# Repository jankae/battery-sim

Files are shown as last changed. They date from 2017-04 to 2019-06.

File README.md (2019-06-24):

# battery-sim

## What is it?
The device emulates the behaviour of a battery, essentially it is a two quadrant supply with a configurable internal resistance.

Key features:
* Voltage range: 0 to 18V
* Current range: -3 to +3A
* Resistance range: 0.005 to 6Ohm

## Why was it built?
While developing other hardware meant to test batteries, various batteries in various different states (voltages, internal resistances, ...) were required to test some aspects. Normal batteries could have been used but getting them to (repeatedly!) behave in the necessary way would have been extremely time-consuming. So, this device was created.

It also doubles as a battery charger/discharger and general use supply.

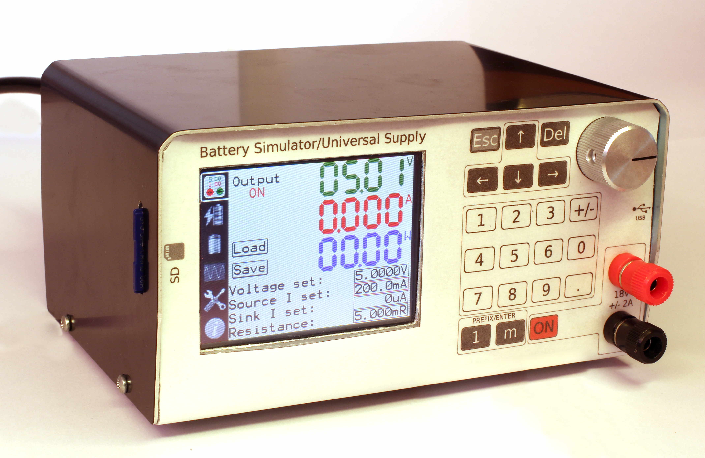
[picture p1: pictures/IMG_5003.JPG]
front1

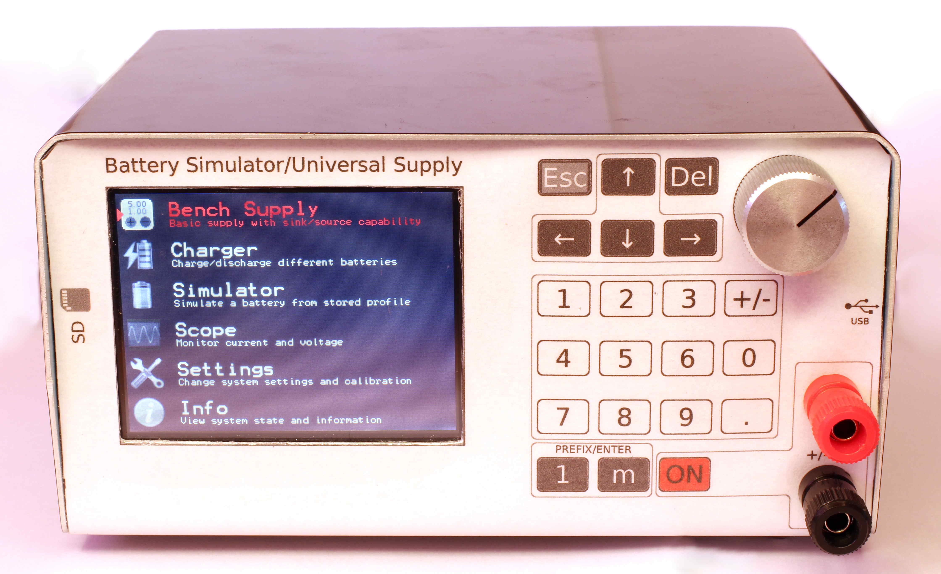
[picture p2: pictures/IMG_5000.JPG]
front2


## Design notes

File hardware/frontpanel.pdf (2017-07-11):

←

↑

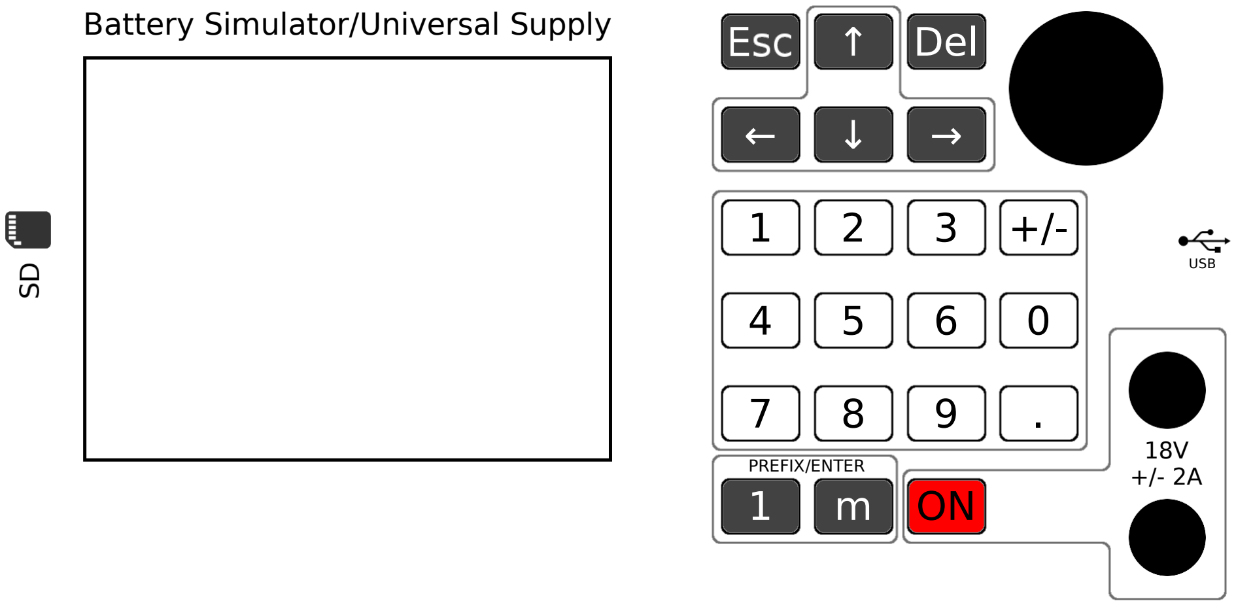
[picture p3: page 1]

Battery Simulator/Universal Supply

PREFIX/ENTER

18V
+/- 2A
ON
1 | 2 | 3
4 | 5 | 6
7 | 8 | 9

0

USB

+/-

→↓

### Del

1 m

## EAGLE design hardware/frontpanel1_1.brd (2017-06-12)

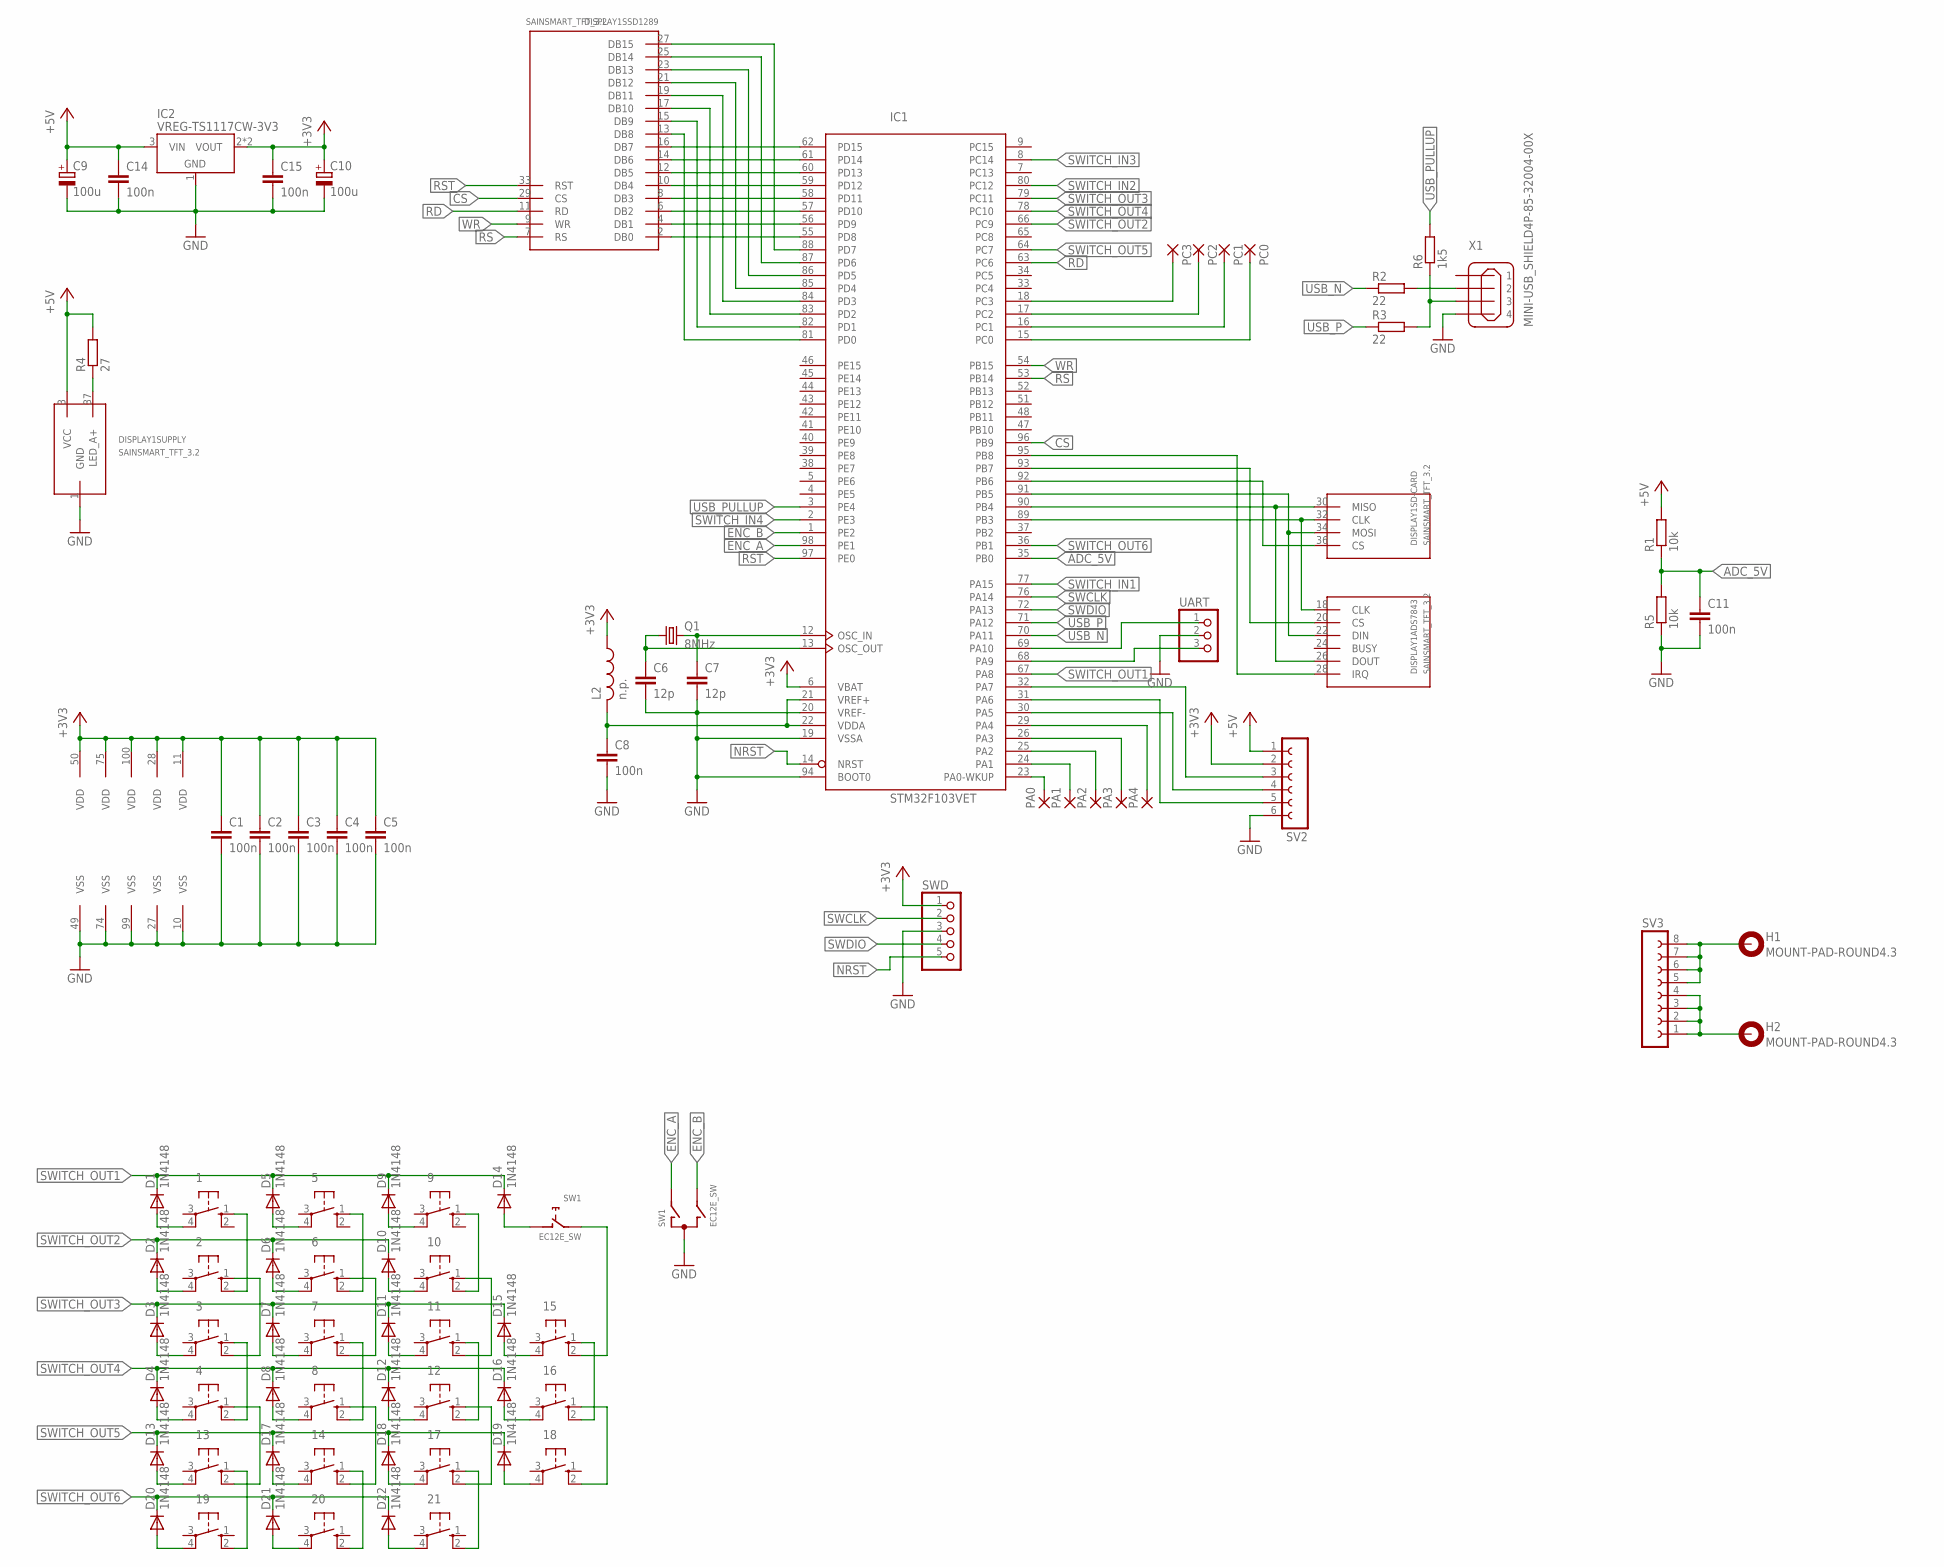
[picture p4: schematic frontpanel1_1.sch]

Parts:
1, 2, 3, 4, 5, 6, 7, 8, 9, 10, 11, 12, 13, 14, 15, 16, 17, 18, 19, 20, 21: 10-XXSMD; SMD
C1, C2, C3, C4, C5, C8, C11, C14, C15: 100n; C0603K
C6, C7: 12p; C0603K
C9, C10: 100u; 153CLV-0505
D1, D2, D3, D4, D5, D6, D7, D8, D9, D10, D11, D12, D13, D14, D15, D16, D17, D18, D19, D20, D21, D22: 1N4148; SOD323-W
DISPLAY1: SAINSMART_TFT_3.2
H1, H2: MOUNT-PAD-ROUND4.3; 4,3-PAD
IC1: STM32F103VET; LQFP100
IC2: VREG-TS1117CW-3V3; SOT223
L2: n.p.; R0603
PA0, PA1, PA2, PA3, PA4: SMD2; SMD1,27-2,54
PC0, PC1, PC2, PC3: SMD2; SMD1,27-2,54
Q1: 8MHz; SM49
R1, R5: 10k; R0603
R2, R3: 22; R0603
R4: 27; R1206
R6: 1k5; R0603
SV2: FE06-1; FE06
SV3: FE08-1; FE08
SW1: EC12E_SW; ALPS_EC12E_SW
SWD: PINHD-1X5; 1X05
UART: PINHD-1X3; 1X03
X1: MINI-USB_SHIELD4P-85-32004-00X; 85-32004-00X

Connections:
+3V3: C1.1, C2.1, C3.1, C4.1, C5.1, C10.+, C15.1, IC1.6 (VBAT), IC1.11 (VDD), IC1.28 (VDD), IC1.50 (VDD), IC1.75 (VDD), IC1.100 (VDD), IC2.2 (VOUT), IC2.4 (VOUT), L2.1, SV2.2, SWD.1
+5V: C9.+, C14.1, DISPLAY1.3 (VCC), IC2.3 (VIN), R1.2, R4.2, SV2.1
ADC_5V: C11.1, IC1.35 (PB0), R1.1, R5.2
CS: DISPLAY1.29 (CS), IC1.96 (PB9)
ENC_A: IC1.98 (PE1), SW1.A
ENC_B: IC1.1 (PE2), SW1.B
EXT4: C8.1, IC1.21 (VREF+), IC1.22 (VDDA), L2.2
GND: C1.2, C2.2, C3.2, C4.2, C5.2, C6.2, C7.2, C8.2, C9.-, C10.-, C11.2, C14.2, C15.2, DISPLAY1.1 (GND), IC1.10 (VSS), IC1.19 (VSSA), IC1.20 (VREF-), IC1.27 (VSS), IC1.49 (VSS), IC1.74 (VSS), IC1.94 (BOOT0), IC1.99 (VSS), IC2.1 (GND), R5.1, SV2.6, SW1.C, SWD.3, UART.2, X1.4
MISO: IC1.31 (PA6), SV2.5
MOSI: IC1.32 (PA7), SV2.3
unnamed: IC1.15 (PC0), PC0.1
unnamed: C7.1, IC1.12 (OSC_IN), Q1.2
unnamed: C6.1, IC1.13 (OSC_OUT), Q1.1
unnamed: DISPLAY1.2 (DB0), IC1.55 (PD8)
unnamed: DISPLAY1.4 (DB1), IC1.56 (PD9)
unnamed: DISPLAY1.6 (DB2), IC1.57 (PD10)
unnamed: DISPLAY1.8 (DB3), IC1.58 (PD11)
unnamed: DISPLAY1.10 (DB4), IC1.59 (PD12)
unnamed: DISPLAY1.12 (DB5), IC1.60 (PD13)
unnamed: DISPLAY1.14 (DB6), IC1.61 (PD14)
unnamed: DISPLAY1.16 (DB7), IC1.62 (PD15)
unnamed: DISPLAY1.15 (DB9), IC1.82 (PD1)
unnamed: DISPLAY1.17 (DB10), IC1.83 (PD2)
unnamed: DISPLAY1.13 (DB8), IC1.81 (PD0)
unnamed: DISPLAY1.19 (DB11), IC1.84 (PD3)
unnamed: DISPLAY1.21 (DB12), IC1.85 (PD4)
unnamed: DISPLAY1.23 (DB13), IC1.86 (PD5)
unnamed: DISPLAY1.25 (DB14), IC1.87 (PD6)
unnamed: DISPLAY1.27 (DB15), IC1.88 (PD7)
unnamed: 13.1 (S), 19.2 (S1)
unnamed: 4.1 (S), 13.2 (S1)
unnamed: 13.4 (P1), D13.A
unnamed: 14.4 (P1), D17.A
unnamed: 17.4 (P1), D18.A
unnamed: 18.4 (P1), D19.A
unnamed: 19.4 (P1), D20.A
unnamed: 20.4 (P1), D21.A
unnamed: 21.4 (P1), D22.A
unnamed: IC1.16 (PC1), PC1.1
unnamed: IC1.17 (PC2), PC2.1
unnamed: IC1.18 (PC3), PC3.1
unnamed: IC1.23 (PA0-WKUP), PA0.1
unnamed: 2.1 (S), 3.2 (S1)
unnamed: 1.1 (S), 2.2 (S1)
unnamed: 5.1 (S), 6.2 (S1)
unnamed: 6.1 (S), 7.2 (S1)
unnamed: IC1.24 (PA1), PA1.1
unnamed: 8.1 (S), 14.2 (S1)
unnamed: 14.1 (S), 20.2 (S1)
unnamed: 17.1 (S), 21.2 (S1)
unnamed: IC1.25 (PA2), PA2.1
unnamed: R2.2, X1.2
unnamed: R3.2, R6.1, X1.3
unnamed: DISPLAY1.37 (LED_A+), R4.1
unnamed: IC1.26 (PA3), PA3.1
unnamed: DISPLAY1.22 (DIN), DISPLAY1.34 (MOSI), IC1.91 (PB5)
unnamed: 4.4 (P1), D4.A
unnamed: 3.4 (P1), D3.A
unnamed: 2.4 (P1), D2.A
unnamed: 1.4 (P1), D1.A
unnamed: DISPLAY1.26 (DOUT), DISPLAY1.30 (MISO), IC1.90 (PB4)
unnamed: DISPLAY1.18 (CLK), DISPLAY1.32 (CLK), IC1.89 (PB3)
unnamed: 11.1 (S), 12.2 (S1)
unnamed: 8.4 (P1), D8.A
unnamed: 7.4 (P1), D7.A
unnamed: 6.4 (P1), D6.A
unnamed: 5.4 (P1), D5.A
unnamed: 10.1 (S), 11.2 (S1)
unnamed: 9.1 (S), 10.2 (S1)
unnamed: 15.1 (S), 16.2 (S1)
unnamed: 12.4 (P1), D12.A
unnamed: 11.4 (P1), D11.A
unnamed: 10.4 (P1), D10.A
unnamed: 9.4 (P1), D9.A
unnamed: IC1.29 (PA4), PA4.1
unnamed: DISPLAY1.36 (CS), IC1.92 (PB6)
unnamed: DISPLAY1.20 (CS), IC1.93 (PB7)
unnamed: 16.4 (P1), D16.A
unnamed: 15.4 (P1), D15.A
unnamed: D14.A, SW1.D (1)
unnamed: DISPLAY1.28 (IRQ), IC1.95 (PB8)
unnamed: 15.2 (S1), SW1.E (2)
NRST: IC1.14 (NRST), SWD.5
OUT+: H2.B4,3, SV3.1, SV3.2, SV3.3, SV3.4
OUT-: H1.B4,3, SV3.5, SV3.6, SV3.7, SV3.8
RD: DISPLAY1.11 (RD), IC1.63 (PC6)
RS: DISPLAY1.7 (RS), IC1.53 (PB14)
RST: DISPLAY1.33 (RST), IC1.97 (PE0)
RX: IC1.69 (PA10), UART.1
SCK: IC1.30 (PA5), SV2.4
SWCLK: IC1.76 (PA14), SWD.2
SWDIO: IC1.72 (PA13), SWD.4
SWITCH_IN1: 3.1 (S), 4.2 (S1), IC1.77 (PA15)
SWITCH_IN2: 7.1 (S), 8.2 (S1), IC1.80 (PC12)
SWITCH_IN3: 12.1 (S), 17.2 (S1), IC1.8 (PC14)
SWITCH_IN4: 16.1 (S), 18.2 (S1), IC1.2 (PE3)
SWITCH_OUT1: D1.C, D5.C, D9.C, D14.C, IC1.67 (PA8)
SWITCH_OUT2: D2.C, D6.C, D10.C, IC1.66 (PC9)
SWITCH_OUT3: D3.C, D7.C, D11.C, D15.C, IC1.79 (PC11)
SWITCH_OUT4: D4.C, D8.C, D12.C, D16.C, IC1.78 (PC10)
SWITCH_OUT5: D13.C, D17.C, D18.C, D19.C, IC1.64 (PC7)
SWITCH_OUT6: D20.C, D21.C, D22.C, IC1.36 (PB1)
TX: IC1.68 (PA9), UART.3
USB_N: IC1.70 (PA11), R2.1
USB_P: IC1.71 (PA12), R3.1
USB_PULLUP: IC1.3 (PE4), R6.2
WR: DISPLAY1.9 (WR), IC1.54 (PB15)

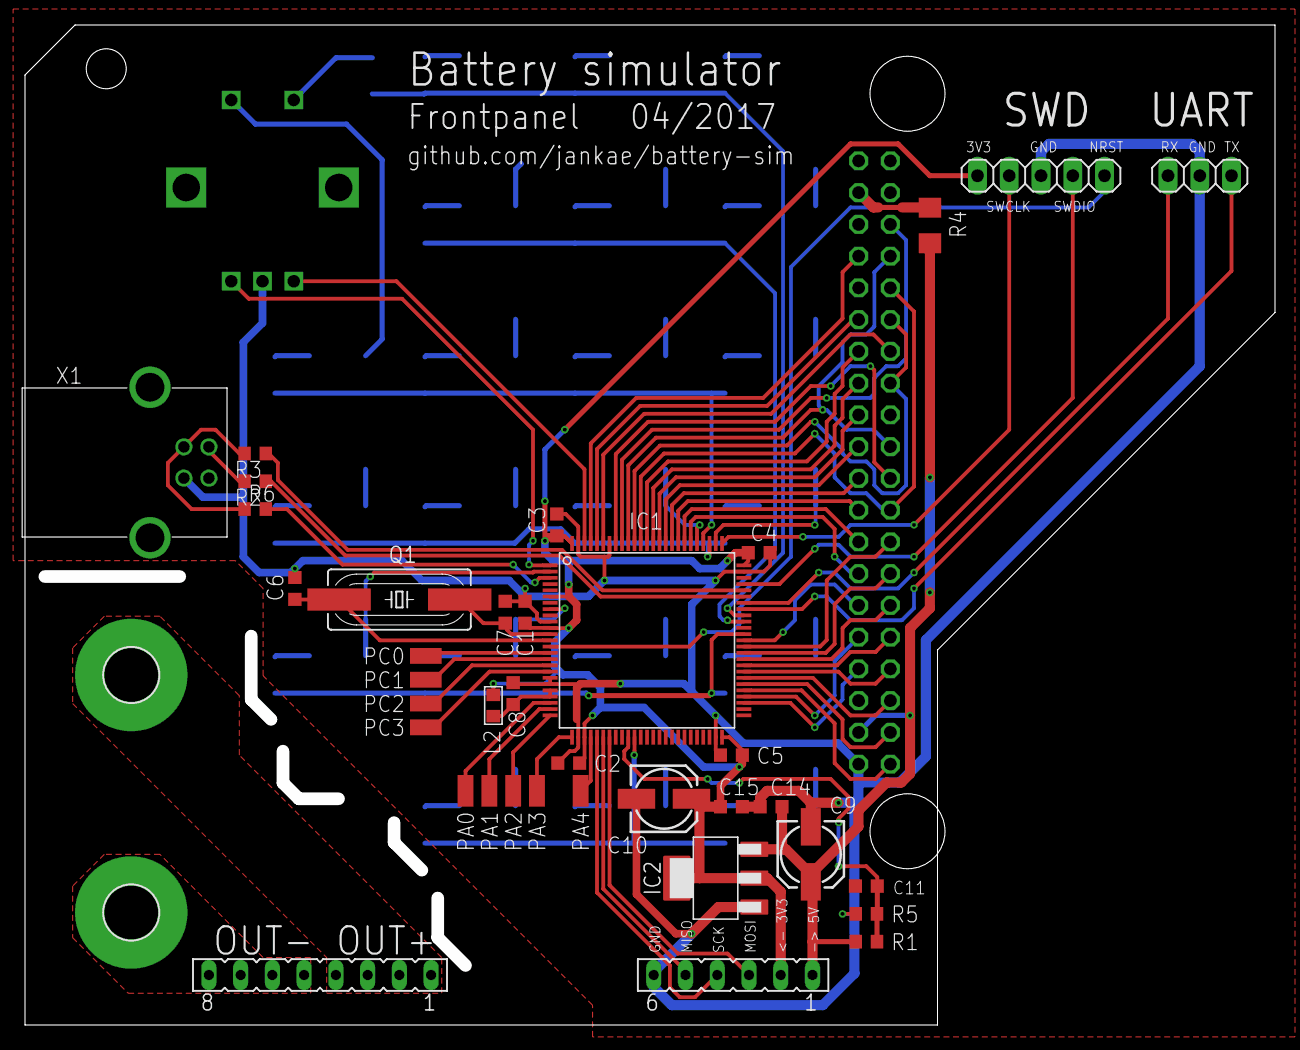
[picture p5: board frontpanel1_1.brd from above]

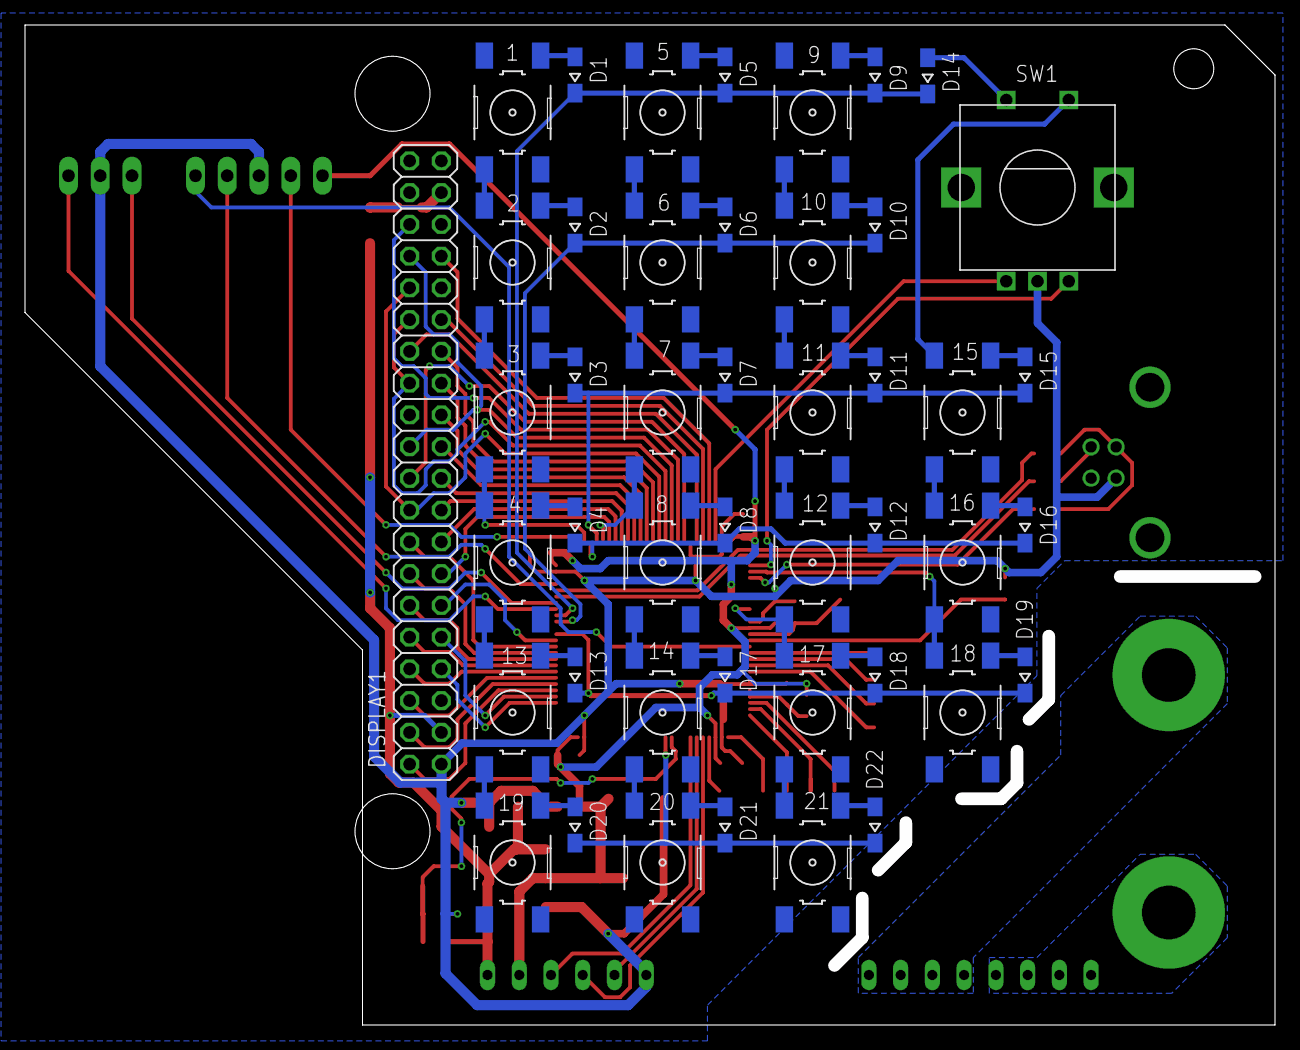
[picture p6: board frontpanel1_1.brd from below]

Board: 2 copper layers, 100.0 x 80.0 mm, 84 parts (45 on the bottom side), 107 nets.

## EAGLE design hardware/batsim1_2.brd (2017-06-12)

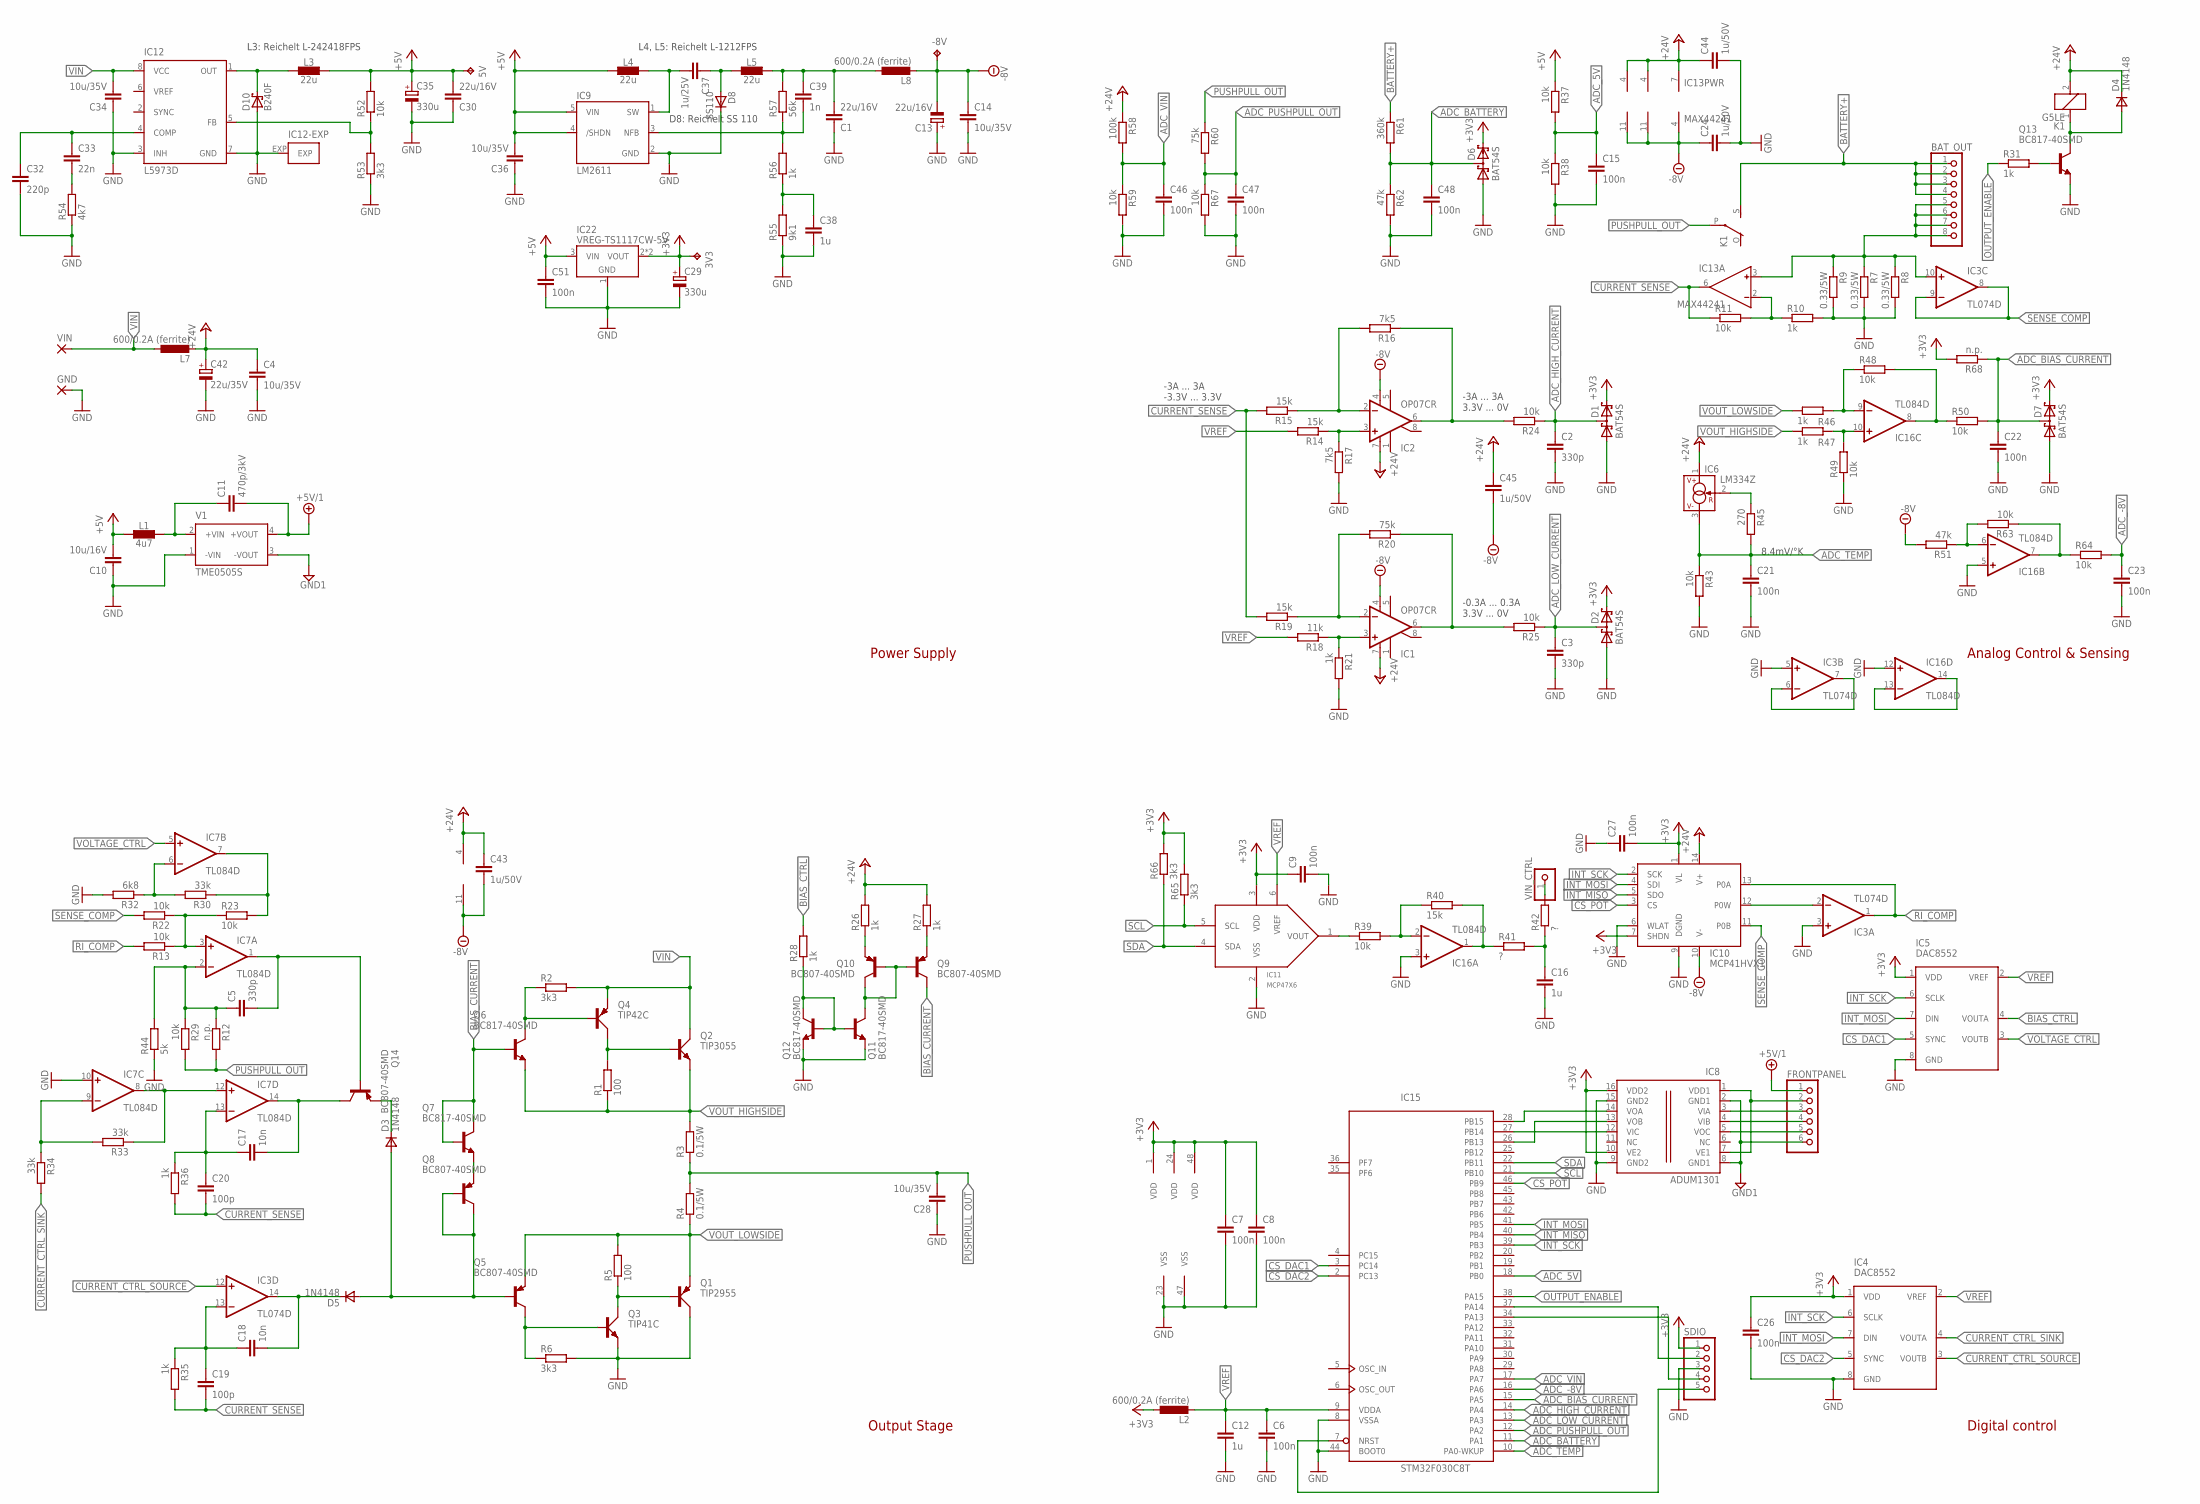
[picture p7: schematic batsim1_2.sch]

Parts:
3V3, 5V: TPB1,27; B1,27
-8V: TPB1,27; B1,27
BAT_OUT: PINHD-1X8/90; 1X08/90
C1, C30: 22u/16V; C1206
C2, C3, C5: 330p; C0603
C4, C14, C28, C34, C36: 10u/35V; C1206
C6, C7, C8, C9, C15, C21, C22, C23, C26, C27, C46, C47, C48, C51: 100n; C0603
C10: 10u/16V; C1206
C11: 470p/3kV; C1812
C12, C16, C38: 1u; C0603
C13: 22u/16V; 153CLV-0505
C17, C18: 10n; C0603
C19, C20: 100p; C0603
C24, C43, C44, C45: 1u/50V; C0603
C29, C35: 330u; 153CLV-0605
C32: 220p; C0603
C33: 22n; C0603
C37: 1u/25V; C1206
C39: 1n; C0603
C42: 22u/35V; 153CLV-0605
D1, D2, D6, D7: BAT54S; SOT23
D3, D4, D5: 1N4148; SOD323
D8: SS110; SMA
D10: B240F; SMB
FRONTPANEL: PINHD-1X6/90; 1X06/90
GND: 3,81/1,4
IC1, IC2: OP07CR; SO08
IC3: TL074D; SO14
IC4, IC5: DAC8552; MSOP8
IC6: LM334Z; TO92
IC7, IC16: TL084D; SO14
IC8: ADUM1301; SO-16W
IC9: LM2611; SOT23-5
IC10: MCP41HVX1; TSSOP14
IC11: MCP47X6; SOT23-6L
IC12: L5973D; HSOP8
IC13: MAX44241; UMAX8
IC15: STM32F030C8T; LQFP48
IC22: VREG-TS1117CW-5V; SOT223
K1: G5LE
L1: 4u7; L_1212
L2, L7, L8: 600/0.2A (ferrite); L2012C
L3: 22u; L_NR60XX
L4, L5: 22u; L_1212
Q1: TIP2955; TOP3AV
Q2: TIP3055; TOP3AV
Q3: TIP41C; TO220AV
Q4: TIP42C; TO220AV
Q5, Q8, Q9, Q10, Q14: BC807-40SMD; SOT23-BEC
Q6, Q7, Q11, Q12, Q13: BC817-40SMD; SOT23-BEC
R1, R5: 100; R0603
R2, R6, R53, R65, R66: 3k3; R0603
R3, R4: 0.1/5W; 5WAXIAL
R7, R8, R9: 0.33/5W; 5WAXIAL
R10, R21, R26, R27, R28, R31, R35, R36, R46, R47, R56: 1k; R0603
R11, R13, R22, R23, R24, R25, R29, R37, R38, R39, R43, R48, R49, R50, R52, R59, R63, R64, R67: 10k; R0603
R12, R68: n.p.; R0603
R14, R15, R19, R40: 15k; R0603
R16, R17: 7k5; R0603
R18: 11k; R0603
R20, R60: 75k; R0603
R30, R33, R34: 33k; R0603
R32: 6k8; R0603
R41, R42: ?; R0603
R44: 5k; R0603
R45: 270; R0603
R51, R62: 47k; R0603
R54: 4k7; R0603
R55: 9k1; R0603
R57: 56k; R0603
R58: 100k; R0603
R61: 360k; R0603
SDIO: PINHD-1X5; 1X05
V1: TME0505S; TME
VIN: 3,81/1,4
VIN_CTRL: PINHD-1X1; 1X01

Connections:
+3V3: 3V3.TP, C7.1, C8.1, C9.1, C26.1, C27.2, C29.+, D1.2 (C2), D2.2 (C2), D6.2 (C2), D7.2 (C2), IC4.1 (VDD), IC5.1 (VDD), IC8.10 (VE2), IC8.16 (VDD2), IC10.1 (VL), IC10.7 (SHDN), IC11.3 (VDD), IC15.1 (VDD), IC15.24 (VDD), IC15.48 (VDD), IC22.2 (VOUT), IC22.4 (VOUT), L2.1, R65.2, R66.2, R68.2, SDIO.1
+5V: 5V.TP, C10.2, C30.2, C35.+, C36.2, C51.1, IC9.4 (/SHDN), IC9.5 (VIN), IC22.3 (VIN), L1.1, L3.2, L4.1, R37.1, R52.2
+5V/1: C11.2, FRONTPANEL.1, V1.4 (+VOUT)
+24V: C4.1, C42.+, C43.1, C44.1, C45.1, D4.1 (C), IC1.7 (V+), IC2.7 (V+), IC3.4 (V+), IC6.1 (V+), IC7.4 (V+), IC10.14 (V+), IC13.7 (V+), IC16.4 (V+), K1.2, L7.2, R26.2, R27.2, R58.1
-8V: -8V.TP, C13.-, C14.1, C24.1, C43.2, C45.2, IC1.4 (V-), IC2.4 (V-), IC3.11 (V-), IC7.11 (V-), IC10.10 (V-), IC13.4 (V-), IC16.11 (V-), L8.2, R51.2
ADC_5V: C15.1, IC15.18 (PB0), R37.2, R38.1
ADC_-8V: C23.1, IC15.16 (PA6), R64.2
ADC_BATTERY: C48.1, D6.3 (C1A2), IC15.11 (PA1), R61.2, R62.1
ADC_BIAS_CURRENT: C22.1, D7.3 (C1A2), IC15.15 (PA5), R50.2, R68.1
ADC_HIGH_CURRENT: C2.1, D1.3 (C1A2), IC15.14 (PA4), R24.1
ADC_LOW_CURRENT: C3.1, D2.3 (C1A2), IC15.13 (PA3), R25.1
ADC_PUSHPULL_OUT: C47.1, IC15.12 (PA2), R60.2, R67.1
ADC_TEMP: C21.1, IC6.3 (V-), IC15.10 (PA0-WKUP), R43.1, R45.2
ADC_VIN: C46.1, IC15.17 (PA7), R58.2, R59.1
BATTERY+: BAT_OUT.1, BAT_OUT.2, BAT_OUT.3, BAT_OUT.4, K1.S, R61.1
BIAS_CTRL: IC5.4 (VOUTA), R28.2
BIAS_CURRENT: Q6.B, Q7.B, Q7.C, Q9.C
CS_DAC1: IC5.5 (SYNC), IC15.3 (PC14)
CS_DAC2: IC4.5 (SYNC), IC15.2 (PC13)
CS_POT: IC10.3 (CS), IC15.46 (PB9)
CURRENT_CTRL_SINK: IC4.4 (VOUTA), R34.2
CURRENT_CTRL_SOURCE: IC3.12 (+IN), IC4.3 (VOUTB)
CURRENT_SENSE: C19.2, C20.2, IC13.6 (OUT), R11.1, R15.2, R19.2, R35.2, R36.2
EXT_MISO: IC8.12 (VIC), IC15.27 (PB14)
EXT_MOSI: IC8.14 (VOA), IC15.28 (PB15)
EXT_SCK: IC8.13 (VOB), IC15.26 (PB13)
GND: C1.1, C2.2, C3.2, C4.2, C6.2, C7.2, C8.2, C9.2, C10.1, C12.2, C13.+, C14.2, C15.2, C16.2, C21.2, C22.2, C23.2, C24.2, C26.2, C27.1, C28.1, C29.-, C30.1, C32.2, C34.1, C35.-, C36.1, C38.2, C42.-, C44.2, C46.2, C47.2, C48.2, C51.2, D1.1 (A1), D2.1 (A1), D6.1 (A1), D7.1 (A1), D8.C, D10.A, GND.1, IC3.3 (+IN), IC3.5 (+IN), IC4.8 (GND), IC5.8 (GND), IC7.10 (+IN), IC8.9 (GND2), IC8.15 (GND2), IC9.2 (GND), IC10.6 (WLAT), IC10.9 (DGND), IC11.2 (VSS), IC12.3 (INH), IC12.7 (GND), IC12.EXP, IC15.8 (VSSA), IC15.23 (VSS), IC15.44 (BOOT0), IC15.47 (VSS), IC16.3 (+IN), IC16.5 (+IN), IC16.12 (+IN), IC22.1 (GND), Q1.C, Q3.E, Q11.E, Q12.E, Q13.E, R6.2, R7.2, R8.2, R9.2, R10.2, R17.2, R21.2, R32.2, R38.2, R43.2, R44.1, R49.1, R53.1, R54.1, R55.1, R59.2, R62.2, R67.2, SDIO.3, V1.1 (-VIN)
GND1: FRONTPANEL.6, IC8.2 (GND1), IC8.8 (GND1), V1.3 (-VOUT)
INT_MISO: IC10.5 (SDO), IC15.40 (PB4)
INT_MOSI: IC4.7 (DIN), IC5.7 (DIN), IC10.4 (SDI), IC15.41 (PB5)
INT_SCK: IC4.6 (SCLK), IC5.6 (SCLK), IC10.2 (SCK), IC15.39 (PB3)
LM2611_SW: C37.2, IC9.1 (SW), L4.2
unnamed: IC7.3 (+IN), R13.1, R22.1, R23.1
unnamed: Q2.B, Q4.C, R1.2
unnamed: Q4.B, Q6.C, R2.1
unnamed: IC7.6 (-IN), R30.2, R32.1
unnamed: BAT_OUT.5, BAT_OUT.6, BAT_OUT.7, BAT_OUT.8, IC3.10 (+IN), IC13.3 (IN+), R7.1, R8.1, R9.1
unnamed: IC16.9 (-IN), R46.2, R48.1
unnamed: Q1.B, Q3.C, R5.1
unnamed: C11.1, L1.2, V1.2 (+VIN)
unnamed: Q3.B, Q5.C, R6.1
unnamed: Q7.E, Q8.E
unnamed: IC7.7 (OUT), R23.2, R30.1
unnamed: D3.1 (C), Q14.E
unnamed: D4.2 (A), K1.1, Q13.C
unnamed: IC13.2 (IN-), R10.1, R11.2
unnamed: IC3.6 (-IN), IC3.7 (OUT)
unnamed: IC2.3 (+IN), R14.1, R17.1
unnamed: IC2.2 (-IN), R15.1, R16.2
unnamed: IC2.6 (OUT), R16.1, R24.2
unnamed: IC1.3 (+IN), R18.1, R21.1
unnamed: IC1.2 (-IN), R19.1, R20.2
unnamed: IC1.6 (OUT), R20.1, R25.2
unnamed: IC3.2 (-IN), IC10.12 (P0W)
unnamed: Q9.B, Q10.B, Q10.C, Q11.C
unnamed: Q11.B, Q12.B, Q12.C, R28.1
unnamed: Q13.B, R31.2
unnamed: IC16.13 (-IN), IC16.14 (OUT)
unnamed: Q10.E, R26.1
unnamed: Q9.E, R27.1
unnamed: C32.1, C33.1, IC12.4 (COMP)
unnamed: C5.2, IC7.1 (OUT), Q14.B
unnamed: IC11.1 (VOUT), R39.1
unnamed: IC7.9 (-IN), R33.2, R34.1
unnamed: IC7.8 (OUT), IC7.12 (+IN), R33.1
unnamed: C18.2, D5.1 (C), IC3.14 (OUT)
unnamed: C18.1, C19.1, IC3.13 (-IN), R35.1
unnamed: C17.2, IC7.14 (OUT), Q14.C
unnamed: IC16.2 (-IN), R39.2, R40.1
unnamed: C17.1, C20.1, IC7.13 (-IN), R36.1
unnamed: IC16.1 (OUT), R40.2, R41.1
unnamed: C16.1, R41.2, R42.1
unnamed: FRONTPANEL.2, IC8.1 (VDD1), IC8.7 (VE1)
unnamed: FRONTPANEL.3, IC8.3 (VIA)
unnamed: FRONTPANEL.4, IC8.4 (VIB)
unnamed: FRONTPANEL.5, IC8.5 (VOC)
unnamed: C33.2, R54.2
unnamed: IC16.10 (+IN), R47.2, R49.2
unnamed: IC6.2 (R), R45.1
unnamed: D10.C, IC12.1 (OUT), L3.1
unnamed: C1.2, C39.1, L5.2, L8.1, R57.2
unnamed: IC12.5 (FB), R52.1, R53.2
unnamed: IC16.8 (OUT), R48.2, R50.1
unnamed: C37.1, D8.A, L5.1
unnamed: C39.2, IC9.3 (NFB), R56.2, R57.1
unnamed: C38.1, R55.2, R56.1
unnamed: IC16.6 (-IN), R51.1, R63.2
unnamed: IC16.7 (OUT), R63.1, R64.1
NRST: IC15.7 (NRST), SDIO.5
OUTPUT_ENABLE: IC15.38 (PA15), R31.1
PUSHPULL_CTRL: D3.2 (A), D5.2 (A), Q5.B, Q8.B, Q8.C
PUSHPULL_OUT: C28.2, K1.P, R3.1, R4.2, R12.2, R29.2, R60.1
RI_COMP: IC3.1 (OUT), IC10.13 (P0A), R13.2
SCL: IC11.5 (SCL), IC15.21 (PB10), R65.1
SDA: IC11.4 (SDA), IC15.22 (PB11), R66.1
SENSE_COMP: IC3.8 (OUT), IC3.9 (-IN), IC10.11 (P0B), R22.2
SWCLK: IC15.37 (PA14), SDIO.2
SWDIO: IC15.34 (PA13), SDIO.4
VIN: C34.2, IC12.8 (VCC), L7.1, Q2.C, Q4.E, R2.2, VIN.1
VIN_CTRL: R42.2, VIN_CTRL.1
VOLTAGE_CTRL: IC5.3 (VOUTB), IC7.5 (+IN)
VOLTAGE_FEEDBACK: C5.1, IC7.2 (-IN), R12.1, R29.1, R44.2
VOUT_HIGHSIDE: Q2.E, Q6.E, R1.1, R3.2, R47.1
VOUT_LOWSIDE: Q1.E, Q5.E, R4.1, R5.2, R46.1
VREF: C6.1, C12.1, IC4.2 (VREF), IC5.2 (VREF), IC11.6 (VREF), IC15.9 (VDDA), L2.2, R14.2, R18.2

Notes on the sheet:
Output Stage
Digital control
-3A ... 3A -3.3V ... 3.3V
-3A ... 3A 3.3V ... 0V
-0.3A ... 0.3A 3.3V ... 0V
Analog Control & Sensing
8.4mV/°K
Power Supply
L4, L5: Reichelt L-1212FPS
L3: Reichelt L-242418FPS
D8: Reichelt SS 110

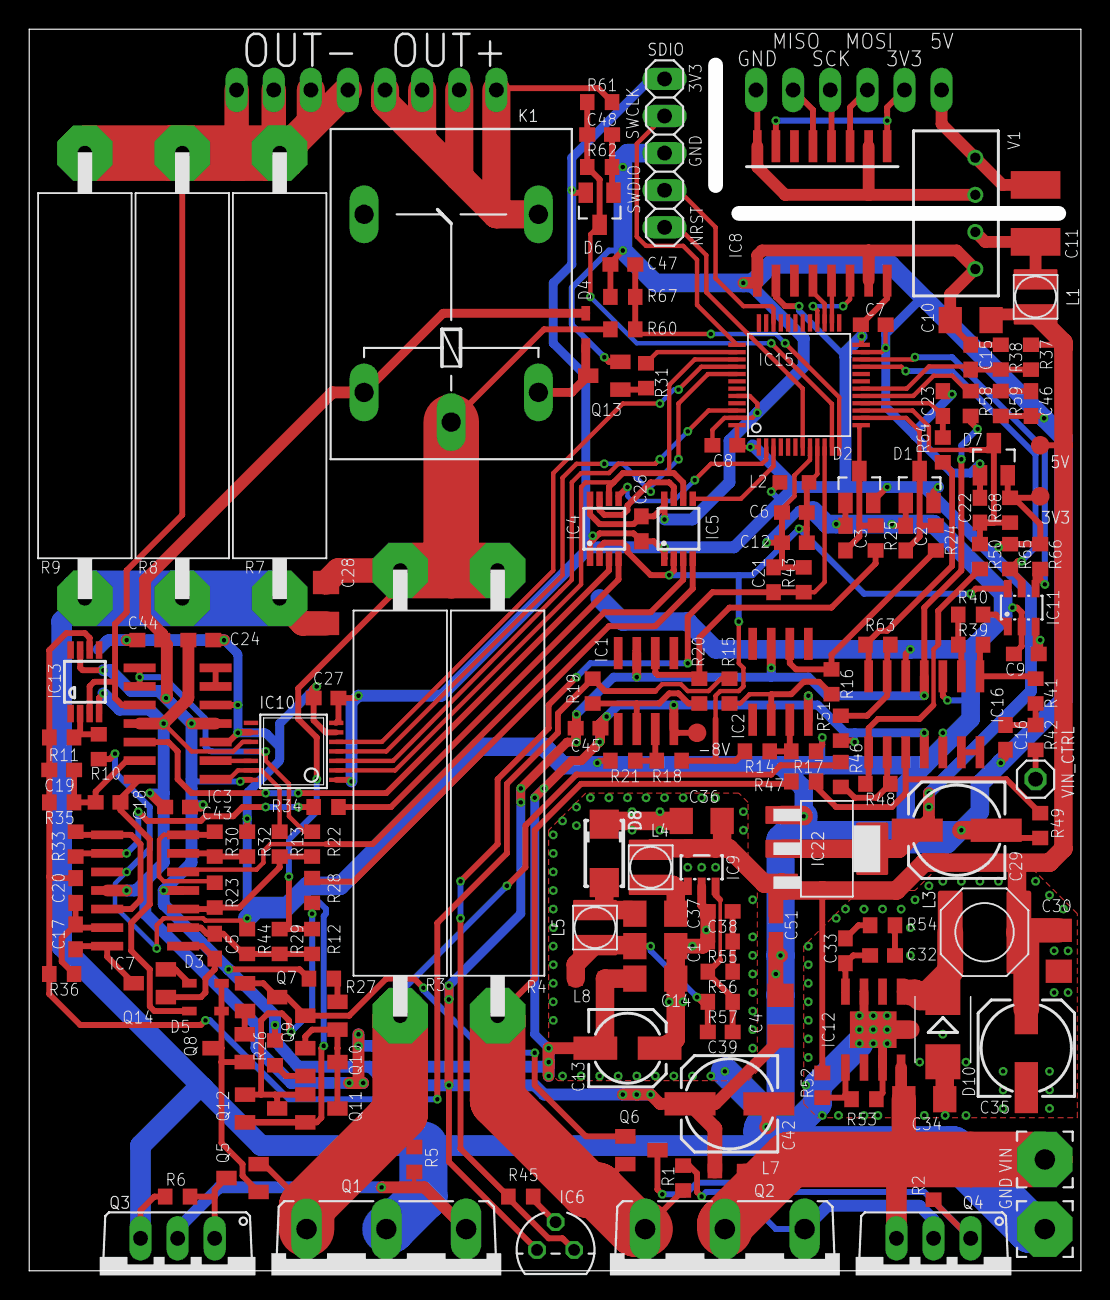
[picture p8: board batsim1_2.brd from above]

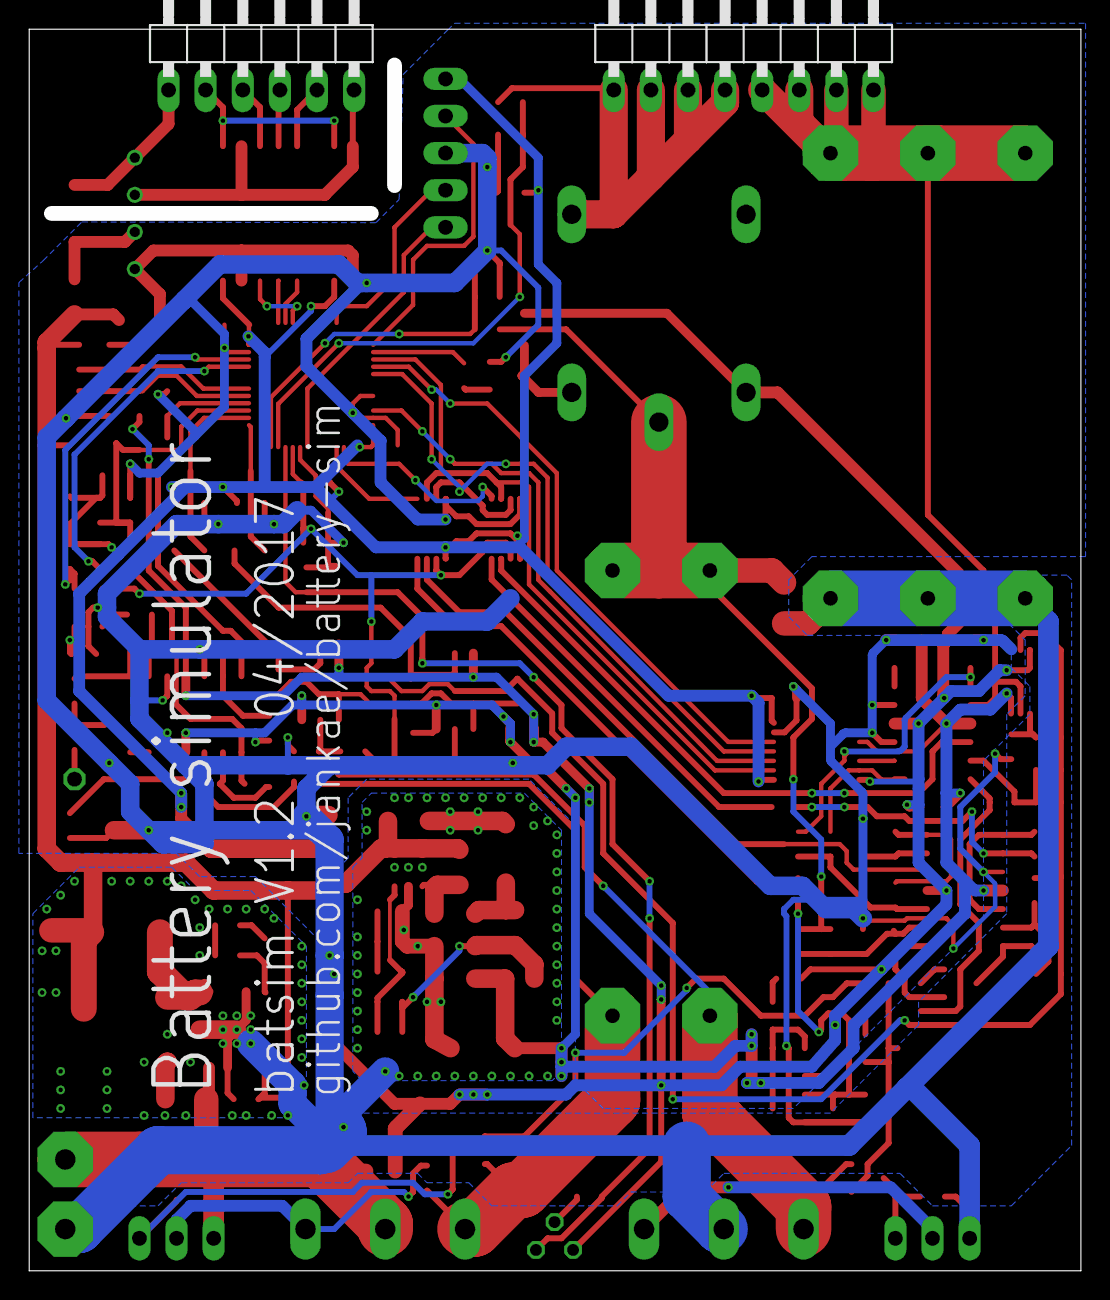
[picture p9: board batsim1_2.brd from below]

Board: 2 copper layers, 72.0 x 85.0 mm, 170 parts (2 on the bottom side), 105 nets.

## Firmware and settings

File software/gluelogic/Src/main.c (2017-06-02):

/**
  ******************************************************************************
  * File Name          : main.c
  * Description        : Main program body
  ******************************************************************************
  *
  * COPYRIGHT(c) 2017 STMicroelectronics
  *
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
  ******************************************************************************
  */
/* Includes ------------------------------------------------------------------*/
#include "main.h"
#include "stm32f0xx_hal.h"
#include "adc.h"
#include "dma.h"
#include "i2c.h"
#include "spi.h"
#include "tim.h"
#include "gpio.h"

/* USER CODE BEGIN Includes */
#include "peripheral.h"
/* USER CODE END Includes */


/* USER CODE BEGIN PV */
#define SPI_BLOCK_SIZE        10
/* SPI block words */
#define SPI_COMMAND_WORD      0
#define SPI_DAC1_CH_A         1
#define SPI_DAC1_CH_B         2
#define SPI_DAC2_CH_A         3
#define SPI_DAC2_CH_B         4
#define SPI_DAC3              5
#define SPI_POT               6

/* SPI command word flags */
#define SPI_COMMAND_OUTPUT    0x01
#define SPI_COMMAND_DAC1_CH_A 0x02
#define SPI_COMMAND_DAC1_CH_B 0x04
#define SPI_COMMAND_DAC2_CH_A 0x08
#define SPI_COMMAND_DAC2_CH_B 0x10
#define SPI_COMMAND_DAC3      0x20
#define SPI_COMMAND_POT       0x40


uint32_t adcSum[SPI_BLOCK_SIZE];
uint16_t nValues;
uint16_t adcBuffer[SPI_BLOCK_SIZE];

uint16_t adcData[SPI_BLOCK_SIZE];
uint16_t spiCtrl[SPI_BLOCK_SIZE];
uint16_t lastCtrl[SPI_BLOCK_SIZE];
//uint16_t dummyData[10] = {1,2,3,4,5,6,7,8,9,10};

extern ADC_HandleTypeDef hadc;
extern SPI_HandleTypeDef hspi2;
extern TIM_HandleTypeDef htim6;
/* USER CODE END PV */

void SystemClock_Config(void);
void Error_Handler(void);

/* USER CODE BEGIN PFP */

void transferComplete(void) {
	/* handle received commands */
	if (spiCtrl[SPI_COMMAND_WORD] & SPI_COMMAND_OUTPUT) {
		/* enable output relay */
		HAL_GPIO_WritePin(OUTPUT_ENABLE_GPIO_Port, OUTPUT_ENABLE_Pin,
				GPIO_PIN_SET);
	} else {
		/* disable output relay */
		HAL_GPIO_WritePin(OUTPUT_ENABLE_GPIO_Port, OUTPUT_ENABLE_Pin,
				GPIO_PIN_RESET);
	}

	/* Relay DAC data */
	if (spiCtrl[SPI_DAC1_CH_A] != lastCtrl[SPI_DAC1_CH_A]) {
		DAC8552_SetChannel(0, 0, spiCtrl[SPI_DAC1_CH_A]);
	}
	if (spiCtrl[SPI_DAC1_CH_B] != lastCtrl[SPI_DAC1_CH_B]) {
		DAC8552_SetChannel(0, 1, spiCtrl[SPI_DAC1_CH_B]);
	}
	if (spiCtrl[SPI_DAC2_CH_A] != lastCtrl[SPI_DAC2_CH_A]) {
		DAC8552_SetChannel(1, 0, spiCtrl[SPI_DAC2_CH_A]);
	}
	if (spiCtrl[SPI_DAC2_CH_B] != lastCtrl[SPI_DAC2_CH_B]) {
		DAC8552_SetChannel(1, 1, spiCtrl[SPI_DAC2_CH_B]);
	}
	if (spiCtrl[SPI_DAC3] != lastCtrl[SPI_DAC3]) {
		MCP47X6_SetChannel(spiCtrl[SPI_DAC3]);
	}
	/* Relay digital potentiometer data */
	if (spiCtrl[SPI_POT] != lastCtrl[SPI_POT]) {
		MCP41HVX1_SetWiper(spiCtrl[SPI_POT]);
	}
	uint8_t i;
	for (i = 0; i < SPI_BLOCK_SIZE; i++) {
		/* Store control words for detection of changes */
		lastCtrl[i] = spiCtrl[i];
		/* load ADC values into SPI data for next transmission */
		adcData[i] = adcSum[i] / nValues;
		adcSum[i] = 0;
	}
	nValues = 0;
}

void startSPITransfer(void) {
	/* synchronize with master, this is necessary because NSS line is not available */
//	HAL_SPI_Abort(&hspi2);
	/* wait for idle clock, SCL will never be low for more than 2us if transmission is active */
	uint16_t idleSince = TIM6->CNT;
	do {
		if (GPIOB->IDR & GPIO_PIN_13) {
			__HAL_RCC_SPI2_FORCE_RESET();
			__HAL_RCC_SPI2_RELEASE_RESET();
			MX_SPI2_Init();
			/* clock is high, reset timeout */
			idleSince = TIM6->CNT;
		}
	} while (TIM6->CNT - idleSince < 8);
	/* now the SPI is between transmissions and we start at the beginning of a frame */
	HAL_SPI_TransmitReceive_DMA(&hspi2, (uint8_t*) adcData, (uint8_t*) spiCtrl,
			SPI_BLOCK_SIZE);
}
/* USER CODE END PFP */

/* USER CODE BEGIN 0 */

void HAL_SPI_TxRxCpltCallback(SPI_HandleTypeDef *hspi) {
	/* apply transferred control commands */
	transferComplete();
	/* restart SPI for the next transfer */
	startSPITransfer();
}

void HAL_ADC_ConvCpltCallback(ADC_HandleTypeDef* hadc) {
	/* Copy ADC values */
	adcSum[0] += adcBuffer[0];
	adcSum[1] += adcBuffer[1];
	adcSum[2] += adcBuffer[2];
	adcSum[3] += adcBuffer[3];
	adcSum[4] += adcBuffer[4];
	adcSum[5] += adcBuffer[5];
	adcSum[6] += adcBuffer[6];
	adcSum[7] += adcBuffer[7];
	adcSum[8] += adcBuffer[8];
	adcSum[9] += adcBuffer[9];
	/* one more sample acquired */
	nValues++;
}
/* USER CODE END 0 */

int main(void)
{

  /* MCU Configuration----------------------------------------------------------*/

  /* Reset of all peripherals, Initializes the Flash interface and the Systick. */
  HAL_Init();

  /* Configure the system clock */
  SystemClock_Config();

  /* Initialize all configured peripherals */
  MX_GPIO_Init();
  MX_DMA_Init();
  MX_ADC_Init();
  MX_I2C2_Init();
  MX_SPI1_Init();
  MX_SPI2_Init();
  MX_TIM6_Init();

  /* USER CODE BEGIN 2 */
  HAL_ADCEx_Calibration_Start(&hadc);

  HAL_TIM_Base_Start(&htim6);
  /* Initialize external DACs */
  Peripheral_Init();
  /* Start ADC sampling */
  HAL_ADC_Start_DMA(&hadc, (uint32_t*)adcBuffer, SPI_BLOCK_SIZE);

  startSPITransfer();

  /* USER CODE END 2 */

  /* Infinite loop */
  /* USER CODE BEGIN WHILE */
  HAL_SuspendTick();
  while (1) {
	  HAL_PWR_EnterSLEEPMode(PWR_MAINREGULATOR_ON, PWR_SLEEPENTRY_WFI);
  /* USER CODE END WHILE */

  /* USER CODE BEGIN 3 */

  }
  /* USER CODE END 3 */

}

/** System Clock Configuration
*/
void SystemClock_Config(void)
{

  RCC_OscInitTypeDef RCC_OscInitStruct;
  RCC_ClkInitTypeDef RCC_ClkInitStruct;

    /**Initializes the CPU, AHB and APB busses clocks 
    */
  RCC_OscInitStruct.OscillatorType = RCC_OSCILLATORTYPE_HSI|RCC_OSCILLATORTYPE_HSI14;
  RCC_OscInitStruct.HSIState = RCC_HSI_ON;
  RCC_OscInitStruct.HSI14State = RCC_HSI14_ON;
  RCC_OscInitStruct.HSICalibrationValue = 16;
  RCC_OscInitStruct.HSI14CalibrationValue = 16;
  RCC_OscInitStruct.PLL.PLLState = RCC_PLL_ON;
  RCC_OscInitStruct.PLL.PLLSource = RCC_PLLSOURCE_HSI;
  RCC_OscInitStruct.PLL.PLLMUL = RCC_PLL_MUL12;
  RCC_OscInitStruct.PLL.PREDIV = RCC_PREDIV_DIV1;
  if (HAL_RCC_OscConfig(&RCC_OscInitStruct) != HAL_OK)
  {
    Error_Handler();
  }

    /**Initializes the CPU, AHB and APB busses clocks 
    */
  RCC_ClkInitStruct.ClockType = RCC_CLOCKTYPE_HCLK|RCC_CLOCKTYPE_SYSCLK
                              |RCC_CLOCKTYPE_PCLK1;
  RCC_ClkInitStruct.SYSCLKSource = RCC_SYSCLKSOURCE_PLLCLK;
  RCC_ClkInitStruct.AHBCLKDivider = RCC_SYSCLK_DIV1;
  RCC_ClkInitStruct.APB1CLKDivider = RCC_HCLK_DIV1;

  if (HAL_RCC_ClockConfig(&RCC_ClkInitStruct, FLASH_LATENCY_1) != HAL_OK)
  {
    Error_Handler();
  }

    /**Configure the Systick interrupt time 
    */
  HAL_SYSTICK_Config(HAL_RCC_GetHCLKFreq()/1000);

    /**Configure the Systick 
    */
  HAL_SYSTICK_CLKSourceConfig(SYSTICK_CLKSOURCE_HCLK);

  /* SysTick_IRQn interrupt configuration */
  HAL_NVIC_SetPriority(SysTick_IRQn, 0, 0);
}

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


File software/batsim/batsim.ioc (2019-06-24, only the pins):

Mcu.UserName=STM32F103VETx
PA10.Signal=USART1_RX
PA11.Signal=USB_DM
PA12.Signal=USB_DP
PA13.Signal=SYS_JTMS-SWDIO
PA14.Signal=SYS_JTCK-SWCLK
PA15.Signal=GPIO_Input
PA5.Signal=SPI1_SCK
PA6.Signal=SPI1_MISO
PA7.Signal=SPI1_MOSI
PA8.Signal=GPIO_Output
PA9.Signal=USART1_TX
PB0.Signal=ADCx_IN8
PB1.Signal=GPIO_Output
PB14.Signal=GPIO_Output
PB15.Signal=GPIO_Output
PB3.Signal=SPI3_SCK
PB4.Signal=SPI3_MISO
PB5.Signal=SPI3_MOSI
PB6.Signal=GPIO_Output
PB7.Signal=GPIO_Output
PB8.Signal=GPIO_Input
PB9.Signal=GPIO_Output
PC10.Signal=GPIO_Output
PC11.Signal=GPIO_Output
PC12.Signal=GPIO_Input
PC14-OSC32_IN.Signal=GPIO_Input
PC6.Signal=GPIO_Output
PC7.Signal=GPIO_Output
PC9.Signal=GPIO_Output
PD0.Signal=GPIO_Output
PD1.Signal=GPIO_Output
PD10.Signal=GPIO_Output
PD11.Signal=GPIO_Output
PD12.Signal=GPIO_Output
PD13.Signal=GPIO_Output
PD14.Signal=GPIO_Output
PD15.Signal=GPIO_Output
PD2.Signal=GPIO_Output
PD3.Signal=GPIO_Output
PD4.Signal=GPIO_Output
PD5.Signal=GPIO_Output
PD6.Signal=GPIO_Output
PD7.Signal=GPIO_Output
PD8.Signal=GPIO_Output
PD9.Signal=GPIO_Output
PE0.Signal=GPIO_Output
PE1.Signal=GPIO_Input
PE2.Signal=GPIO_Input
PE3.Signal=GPIO_Input

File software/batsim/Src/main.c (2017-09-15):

/**
  ******************************************************************************
  * File Name          : main.c
  * Description        : Main program body
  ******************************************************************************
  * This notice applies to any and all portions of this file
  * that are not between comment pairs USER CODE BEGIN and
  * USER CODE END. Other portions of this file, whether 
  * inserted by the user or by software development tools
  * are owned by their respective copyright owners.
  *
  * Copyright (c) 2017 STMicroelectronics International N.V. 
  * All rights reserved.
  *
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
  ******************************************************************************
  */
/* Includes ------------------------------------------------------------------*/
#include "main.h"
#include "stm32f1xx_hal.h"
#include "cmsis_os.h"
#include "adc.h"
#include "dma.h"
#include "fatfs.h"
#include "spi.h"
#include "tim.h"
#include "usart.h"
#include "usb_device.h"
#include "gpio.h"

/* USER CODE BEGIN Includes */
#include "display.h"
#include "pushpull.h"
//#include "touch.h"
#include "logging.h"
/* USER CODE END Includes */


/* USER CODE BEGIN PV */

/* USER CODE END PV */

void SystemClock_Config(void);
void MX_FREERTOS_Init(void);

/* USER CODE BEGIN PFP */

/* USER CODE END PFP */

int main(void)
{

  /* MCU Configuration----------------------------------------------------------*/

  /* Reset of all peripherals, Initializes the Flash interface and the Systick. */
  HAL_Init();

  /* Configure the system clock */
  SystemClock_Config();

  /* Initialize all configured peripherals */
  MX_GPIO_Init();
  MX_DMA_Init();
  MX_ADC1_Init();
  MX_SPI1_Init();
  MX_SPI3_Init();
  MX_USART1_UART_Init();
  MX_TIM3_Init();

  /* USER CODE BEGIN 2 */
  touch_Init();
  cal_Init();
  pushpull_Init();
  HAL_TIM_Base_Start_IT(&htim3);
  HAL_Delay(100);
  display_Init();
  /* USER CODE END 2 */

  /* Call init function for freertos objects (in freertos.c) */
  MX_FREERTOS_Init();

  /* Start scheduler */
  osKernelStart();
  
  /* We should never get here as control is now taken by the scheduler */

  /* Infinite loop */
  /* USER CODE BEGIN WHILE */
  while (1)
  {
  /* USER CODE END WHILE */

  /* USER CODE BEGIN 3 */

  }
  /* USER CODE END 3 */

}

/** System Clock Configuration
*/
void SystemClock_Config(void)
{

  RCC_OscInitTypeDef RCC_OscInitStruct;
  RCC_ClkInitTypeDef RCC_ClkInitStruct;
  RCC_PeriphCLKInitTypeDef PeriphClkInit;

    /**Initializes the CPU, AHB and APB busses clocks 
    */
  RCC_OscInitStruct.OscillatorType = RCC_OSCILLATORTYPE_HSE;
  RCC_OscInitStruct.HSEState = RCC_HSE_ON;
  RCC_OscInitStruct.HSEPredivValue = RCC_HSE_PREDIV_DIV1;
  RCC_OscInitStruct.HSIState = RCC_HSI_ON;
  RCC_OscInitStruct.PLL.PLLState = RCC_PLL_ON;
  RCC_OscInitStruct.PLL.PLLSource = RCC_PLLSOURCE_HSE;
  RCC_OscInitStruct.PLL.PLLMUL = RCC_PLL_MUL9;
  if (HAL_RCC_OscConfig(&RCC_OscInitStruct) != HAL_OK)
  {
    _Error_Handler(__FILE__, __LINE__);
  }

    /**Initializes the CPU, AHB and APB busses clocks 
    */
  RCC_ClkInitStruct.ClockType = RCC_CLOCKTYPE_HCLK|RCC_CLOCKTYPE_SYSCLK
                              |RCC_CLOCKTYPE_PCLK1|RCC_CLOCKTYPE_PCLK2;
  RCC_ClkInitStruct.SYSCLKSource = RCC_SYSCLKSOURCE_PLLCLK;
  RCC_ClkInitStruct.AHBCLKDivider = RCC_SYSCLK_DIV1;
  RCC_ClkInitStruct.APB1CLKDivider = RCC_HCLK_DIV2;
  RCC_ClkInitStruct.APB2CLKDivider = RCC_HCLK_DIV1;

  if (HAL_RCC_ClockConfig(&RCC_ClkInitStruct, FLASH_LATENCY_2) != HAL_OK)
  {
    _Error_Handler(__FILE__, __LINE__);
  }

  PeriphClkInit.PeriphClockSelection = RCC_PERIPHCLK_ADC|RCC_PERIPHCLK_USB;
  PeriphClkInit.AdcClockSelection = RCC_ADCPCLK2_DIV6;
  PeriphClkInit.UsbClockSelection = RCC_USBCLKSOURCE_PLL_DIV1_5;
  if (HAL_RCCEx_PeriphCLKConfig(&PeriphClkInit) != HAL_OK)
  {
    _Error_Handler(__FILE__, __LINE__);
  }

    /**Configure the Systick interrupt time 
    */
  HAL_SYSTICK_Config(HAL_RCC_GetHCLKFreq()/1000);

    /**Configure the Systick 
    */
  HAL_SYSTICK_CLKSourceConfig(SYSTICK_CLKSOURCE_HCLK);

  /* SysTick_IRQn interrupt configuration */
  HAL_NVIC_SetPriority(SysTick_IRQn, 15, 0);
}

/* USER CODE BEGIN 4 */
void HAL_SPI_TxRxCpltCallback(SPI_HandleTypeDef *hspi) {
	if (hspi->Instance == SPI1) {
		pushpull_SPIComplete();
	}
}
/* USER CODE END 4 */

/**
  * @brief  Period elapsed callback in non blocking mode
  * @note   This function is called  when TIM2 interrupt took place, inside
  * HAL_TIM_IRQHandler(). It makes a direct call to HAL_IncTick() to increment
  * a global variable "uwTick" used as application time base.
  * @param  htim : TIM handle
  * @retval None
  */
void HAL_TIM_PeriodElapsedCallback(TIM_HandleTypeDef *htim)
{
  if (htim->Instance == TIM2) {
    HAL_IncTick();
  }
}

/**
  * @brief  This function is executed in case of error occurrence.
  * @param  None
  * @retval None
  */
void _Error_Handler(char * file, int line)
{
  /* USER CODE BEGIN Error_Handler_Debug */
  /* User can add his own implementation to report the HAL error return state */
  while(1) 
  {
  }
  /* USER CODE END Error_Handler_Debug */ 
}

#ifdef USE_FULL_ASSERT

/**
   * @brief Reports the name of the source file and the source line number
   * where the assert_param error has occurred.
   * @param file: pointer to the source file name
   * @param line: assert_param error line source number
   * @retval None
   */
void assert_failed(uint8_t* file, uint32_t line)
{
  /* USER CODE BEGIN 6 */
  /* User can add his own implementation to report the file name and line number,
    ex: printf("Wrong parameters value: file %s on line %d\r\n", file, line) */
  /* USER CODE END 6 */

}

#endif

/**
  * @}
  */ 

/**
  * @}
*/ 

/************************ (C) COPYRIGHT STMicroelectronics *****END OF FILE****/

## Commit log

2017-03-14 Initial setup
    [batsim.brd, batsim.sch]
2017-03-29 Touch calibration routine added. TODO: store in FLASH
2017-04-20 PCB files
    [batsim1_1.brd, batsim1_1.sch, batsim1_2.brd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]
2017-04-21 board update
    [batsim1_2.brd, batsim1_2.sch, frontpanel.brd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]
2017-04-21 PCB markings
    [batsim1_2.brd, batsim1_2.sch, frontpanel.brd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]
2017-04-22 minor PCB changes
    [batsim1_2.brd, batsim1_2.sch, frontpanel.brd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]
2017-04-22 final PCB corrections
    [frontpanel.brd, frontpanel.sch]
2017-04-22 Added gerber files
2017-04-23 template code for gluelogic
2017-04-23 Basic glue logic framework
2017-05-01 Switched to STM32F103, initial Cube-Framework
2017-05-02 some adjustments to Makefile and minor changes to remove build errors
    [pushpull.c]
2017-05-02 USB submodule removed (not working anyway) + removed warnings
    [display.c]
2017-05-02 Pin changes according to new PCB layout
2017-05-02 Button matrix evaluation module
2017-05-02 Encoder added to button routine
2017-05-02 Touch: switched from software to hardware SPI + missing Cube changes
    [cubeMX.ioc]
2017-05-18 [gluelogic] SPI synchronisation implemented
2017-05-21 Pictures of partial assembly
2017-05-30 ADC sampling time reduced + Calibration on startup
2017-06-03 Various fixes, getting the buttons and encoder to work
    [cubeMX.ioc, main.c, pushpull.c]
2017-06-06 Bugfixes, GUI improvements, rudimentary bench supply app
    [cubeMX.ioc]
2017-06-06 Config files, ADC improvements, internal Resistance added
2017-06-08 Charger app started, various minor GUI improvements
2017-06-08 Basic charger completed, again minor GUI improvements
2017-06-10 Output calibration
2017-06-11 Calibration of sink current DAC added
2017-06-11 CubeMX update (needs modification after generating!) + USB CDC device
2017-06-12 Info App + temperature monitoring
2017-06-12 Minor hardware + gitignore update
    [batsim1_2.brd, batsim1_2.sch]
2017-06-12 Removed old hardware files, added USB pullup
    [batsim.brd, batsim.sch, batsim1_1.brd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]
2017-06-13 Fix: memory leak in textfield widget + some todos deleted
    [display.c, pushpull.c, startup.c]
2017-06-22 Graph, Battery simulation, minor other fixes
2017-06-26 Bugfixes + beginning of simulator app
    [pushpull.c]
2017-06-26 first battery simulation test
2017-09-14 Name clash fix and other bugs
    [pushpull.c, user_diskio.c]
2017-09-14 Revert CubeMX changes for broken SPI (do not regenerate)
2017-09-14 Adjust verbose calibration check
2017-09-16 CubeMX update, SPI timeout increased, SD card working again
2017-09-16 SD SPI speed increase / some debugging improvements
2017-11-28 Added internal resistance to supply + bugfix on file load
2018-04-01 Navigate and select widgets with arrow buttons
2018-05-10 Calibration routine extendend
    - Overflow in entry string parsing fixed
    - Additional dialog: unit input (easier user input during calibration)
    - Calibration routine bux fixes/calibrating more ranges
2019-06-24 Pictures of finsished device

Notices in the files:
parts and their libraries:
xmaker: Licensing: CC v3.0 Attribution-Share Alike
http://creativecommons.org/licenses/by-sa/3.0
